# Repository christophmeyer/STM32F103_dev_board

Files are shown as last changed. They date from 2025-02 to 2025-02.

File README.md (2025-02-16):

# STM32F103 Development Board

This repo contains the [KiCad](https://www.kicad.org/) hardware design files for a development board for the `STM32F103` MCU, which is somewhat similar to the well known blue pill board. The design(er) has greatly benefitted from some of [Phil Salmony's](https://www.phils-lab.net/) designs :pray:.

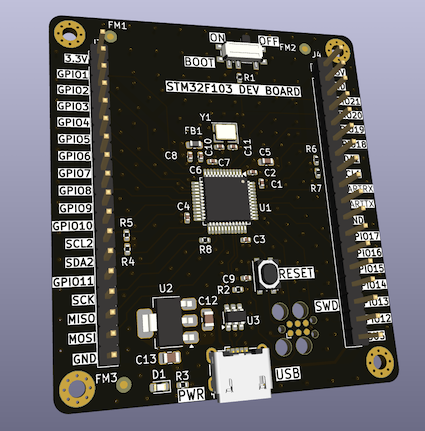
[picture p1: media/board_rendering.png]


## Features

- STM32F103 MCU
  - 2x I2C (pull up resistors included)
  - SPI (22R series termination resistor included)
  - USB micro
  - UART
  - 21 GPIOs
- 16MHz crystal
- ESD protection
- SWD via legged 6-pin plug-of-nails tag-connect connector
- BOOT0 pin toggle switch
- NRST pin push button
- Power LED
- LDO voltage regulator

## Manufacturing

All files necessary for manufacturing the board at the pcb manufacturer of your choice can be found in `./manufacturing_r0.1`. This includes the drill files, gerbers, bill of materials and a basic assembly drawing.

Fully manufactured version of the board:

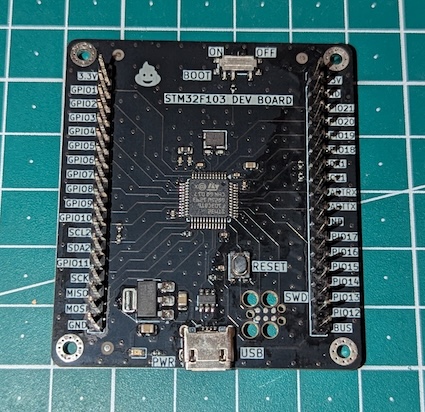
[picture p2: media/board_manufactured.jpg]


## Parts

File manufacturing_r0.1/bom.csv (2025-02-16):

Reference | Value | Datasheet | Footprint | Qty | Description | Manufacturer | Manufacturer Part Number | Distributor Link | Distributor Part Number
C1,C2,C3,C4,C9 | 100n | ~ | Capacitor_SMD:C_0402_1005Metric | 5 | Unpolarized capacitor | KYOCERA AVX | 04023C104KAT2A | https://www.mouser.de/ProductDetail/KYOCERA-AVX/04023C104KAT2A?qs=nNezP%252BoerbAsgsxxIAjFOw%3D%3D | 581-04023C104KAT2A
C5 | 10u | ~ | Capacitor_SMD:C_0603_1608Metric | 1 | Unpolarized capacitor | KYOCERA AVX | 0603YD106KAT2A | https://www.mouser.de/ProductDetail/KYOCERA-AVX/0603YD106KAT2A | 581-0603YD106KAT2A
C6,C8 | 1u | ~ | Capacitor_SMD:C_0402_1005Metric | 2 | Unpolarized capacitor | KYOCERA AVX | 04023D105KAT2A | https://www.mouser.de/ProductDetail/KYOCERA-AVX/04023D105KAT2A | 581-04023D105KAT2A
C7 | 10n | ~ | Capacitor_SMD:C_0402_1005Metric | 1 | Unpolarized capacitor | KYOCERA AVX | 0402YC104JAT4A | https://eu.mouser.com/ProductDetail/KYOCERA-AVX/0402YC104JAT4A | 581-0402YC104JAT4A
C10,C11 | 15p | ~ | Capacitor_SMD:C_0402_1005Metric | 2 | Unpolarized capacitor | KYOCERA AVX | 04025U150JAT2A | https://www.mouser.de/ProductDetail/KYOCERA-AVX/04025U150JAT2A
C12,C13 | 22u | ~ | Capacitor_SMD:C_0805_2012Metric | 2 | Unpolarized capacitor | KYOCERA AVX | 08053D226MAT2A | https://www.mouser.de/ProductDetail/KYOCERA-AVX/08053D226MAT2A?qs=bxXxiBiblXqtZp79ClJbtg%3D%3D | 581-08053D226MAT2A
D1 | LED | ~ | LED_SMD:LED_0603_1608Metric | 1 | Light emitting diode | Würth Elektronik | 150060SS75000 | https://www.digikey.de/en/products/detail/w%C3%BCrth-elektronik/150060SS75000/4489903 | 732-4979-2-ND
FB1 | 120R | ~ | Inductor_SMD:L_0603_1608Metric | 1 | Ferrite bead | Würth Elektronik | 742792606 | https://www.mouser.de/ProductDetail/Wurth-Elektronik/742792606?qs=Wn16VcyqZWrBgQf2cBsziw%3D%3D | 710-742792606
J1 | USB_B_Micro | ~ | Connector_USB:USB_Micro-B_Wuerth_629105150521 | 1 | USB Micro Type B connector | Würth Elektronik | 629105150521 | https://www.digikey.de/en/products/detail/w%C3%BCrth-elektronik/629105150521/5047751 | 732-5960-2-ND
R1 | 10k | ~ | Resistor_SMD:R_0402_1005Metric | 1 | Resistor | Würth Elektronik | 560112110020 | https://www.mouser.de/ProductDetail/Wurth-Elektronik/560112110020?qs=mELouGlnn3fA8%252B%2F79%2FueqA%3D%3D | 710-560112110020
R2,R3,R4,R5,R6,R7 | 1k5 | ~ | Resistor_SMD:R_0402_1005Metric | 6 | Resistor | Würth Elektronik | 560112110095 | https://www.mouser.de/ProductDetail/Wurth-Elektronik/560112110095?qs=mELouGlnn3cs5mmpxmgsuw%3D%3D | 710-560112110095
R8 | 22R | ~ | Resistor_SMD:R_0402_1005Metric | 1 | Resistor | Würth Elektronik | 560112110046 | https://www.mouser.de/ProductDetail/Wurth-Elektronik/560112110046?qs=mELouGlnn3e%252BO26rgRVUuA%3D%3D | 710-560112110046
SW1 | SW_Push | ~ | Button_Switch_SMD:SW_Push_1P1T_NO_Vertical_Wuerth_434133025816 | 1 | Push button switch, generic, two pins | Würth Elektronik | 434133025816 | https://www.digikey.de/en/products/detail/w%C3%BCrth-elektronik/434133025816/9950810 | 732-13663-2-ND
SW2 | SW_SPDT | ~ | Button_Switch_SMD:SW_SPDT_PCM12 | 1 | Switch, single pole double throw | C&K | PCM12SMTR | https://www.digikey.com/en/products/detail/c-k/PCM12SMTR/1640112 | 401-2016-2-ND
U1 | STM32F103C8Tx | https://www.st.com/resource/en/datasheet/stm32f103c8.pdf | Package_QFP:LQFP-48_7x7mm_P0.5mm | 1 | STMicroelectronics Arm Cortex-M3 MCU, 64KB flash, 20KB RAM, 72 MHz, 2.0-3.6V, 37 GPIO, LQFP48 | STMicroelectronics | STM32F103C8T6TR | https://www.digikey.com/en/products/detail/stmicroelectronics/STM32F103C8T6TR/2122442 | 497-17666-2-ND
U2 | AMS1117-3.3 | http://www.advanced-monolithic.com/pdf/ds1117.pdf | Package_TO_SOT_SMD:SOT-223-3_TabPin2 | 1 | 1A Low Dropout regulator, positive, 3.3V fixed output, SOT-223 | UMW | AMS1117-3.3 | https://www.digikey.de/en/products/detail/umw/AMS1117-3-3/17635254 | 4518-AMS1117-3.3TR-ND
U3 | USBLC6-2SC6 | https://www.st.com/resource/en/datasheet/usblc6-2.pdf | Package_TO_SOT_SMD:SOT-23-6 | 1 | Very low capacitance ESD protection diode, 2 data-line, SOT-23-6 | STMicroelectronics | USBLC6-2SC6Y | https://www.mouser.de/ProductDetail/STMicroelectronics/USBLC6-2SC6Y?qs=gNDSiZmRJS%2FOgDexvXkdow%3D%3D | 511-USBLC6-2SC6Y
Y1 | 16MHz | ~ | Crystal:Crystal_SMD_3225-4Pin_3.2x2.5mm | 1 | Four pin crystal, GND on pins 2 and 4 | NDK | NX3225GA-16.000M-STD-CRG-2 | https://www.mouser.in/ProductDetail/NDK/NX3225GA-16.000M-STD-CRG-2?qs=55YtniHzbhBNECTNQGAQ8A%3D%3D | 344-NX3225GA16MCRG2

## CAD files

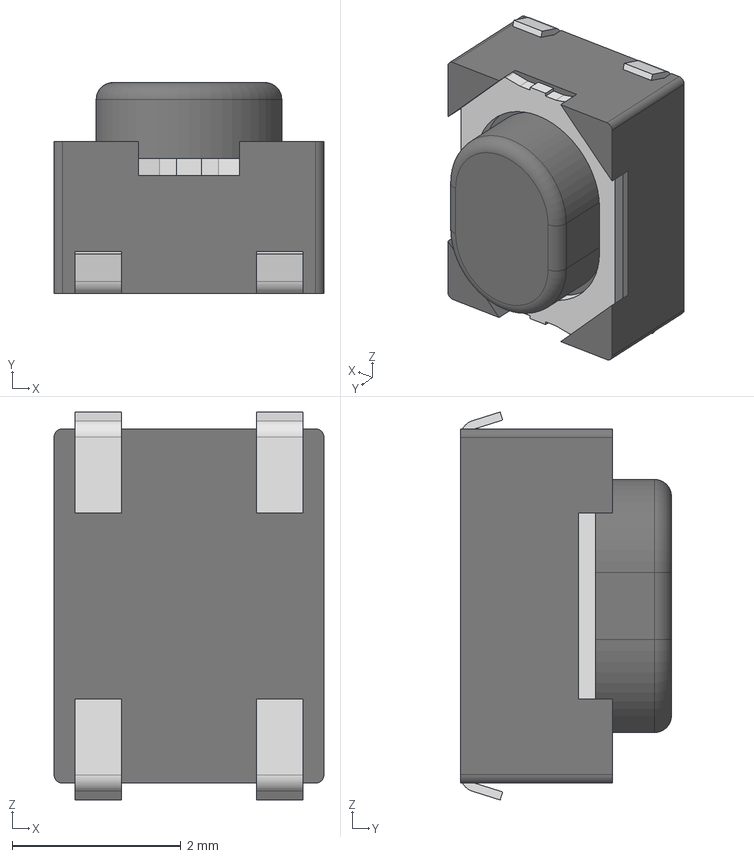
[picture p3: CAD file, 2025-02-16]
3d_models/STP_4341x30258x6_rev1.stp
3.20 x 2.50 x 4.60 mm
Frame
Cover
Stem
Terminal x 4

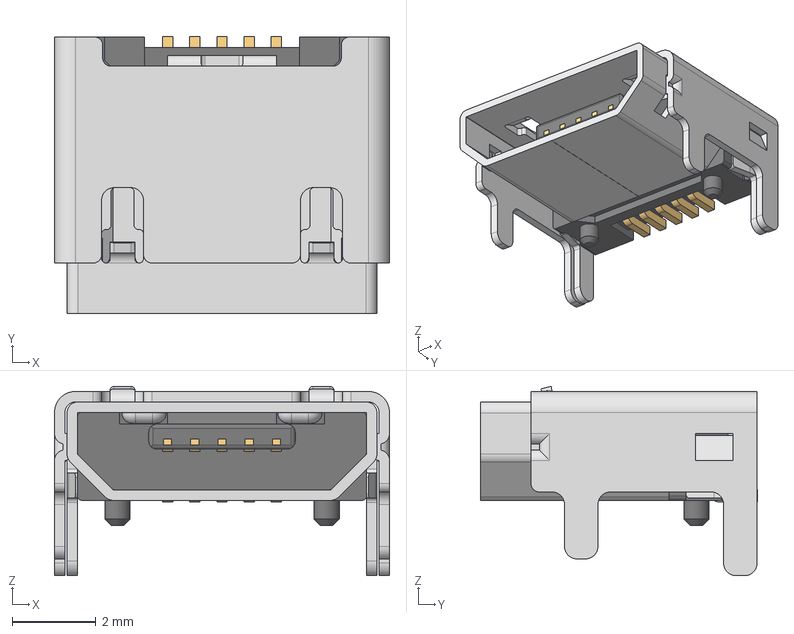
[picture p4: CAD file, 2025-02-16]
3d_models/629105150521 (rev1).stp
8.00 x 6.60 x 4.52 mm
629105150521_Housing
629105150521_Pin1 x 4
629105150521_Pin2
629105150521_Shielding2
629105150521_Shielding

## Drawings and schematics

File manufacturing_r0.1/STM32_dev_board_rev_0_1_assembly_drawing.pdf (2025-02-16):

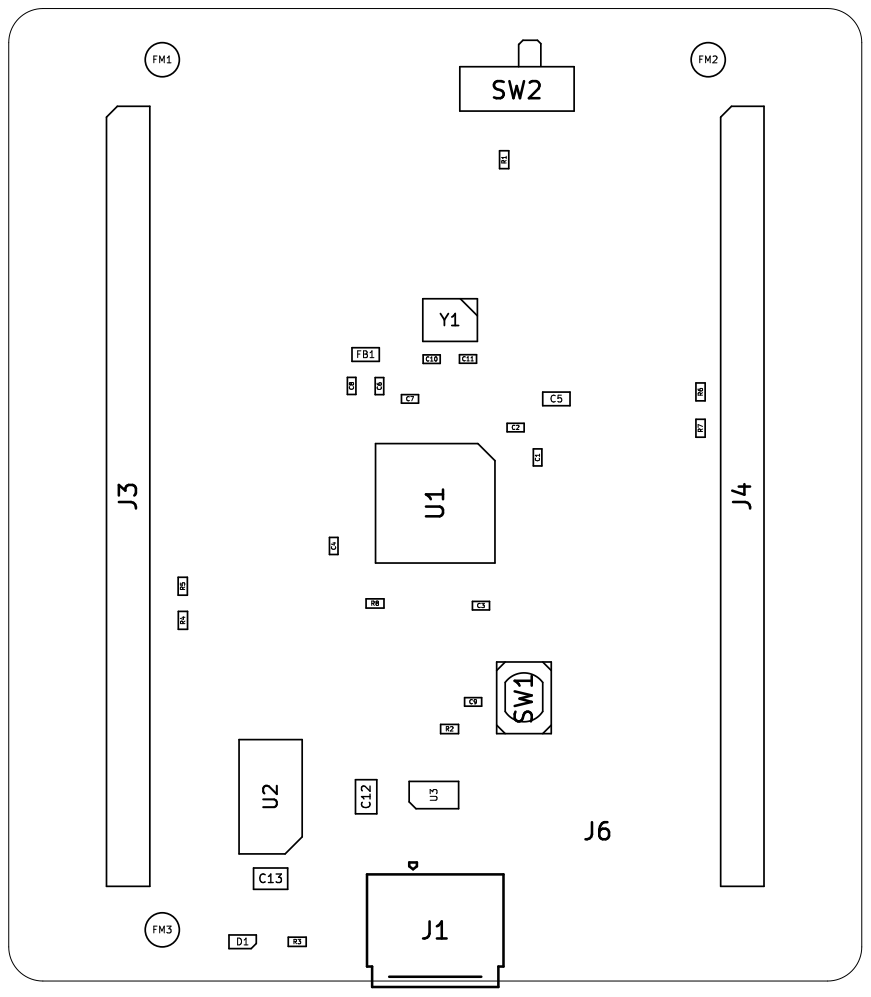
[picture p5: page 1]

Id: 1/1 Title: File: STM32_dev_board.kicad_pcb Sheet: SW1

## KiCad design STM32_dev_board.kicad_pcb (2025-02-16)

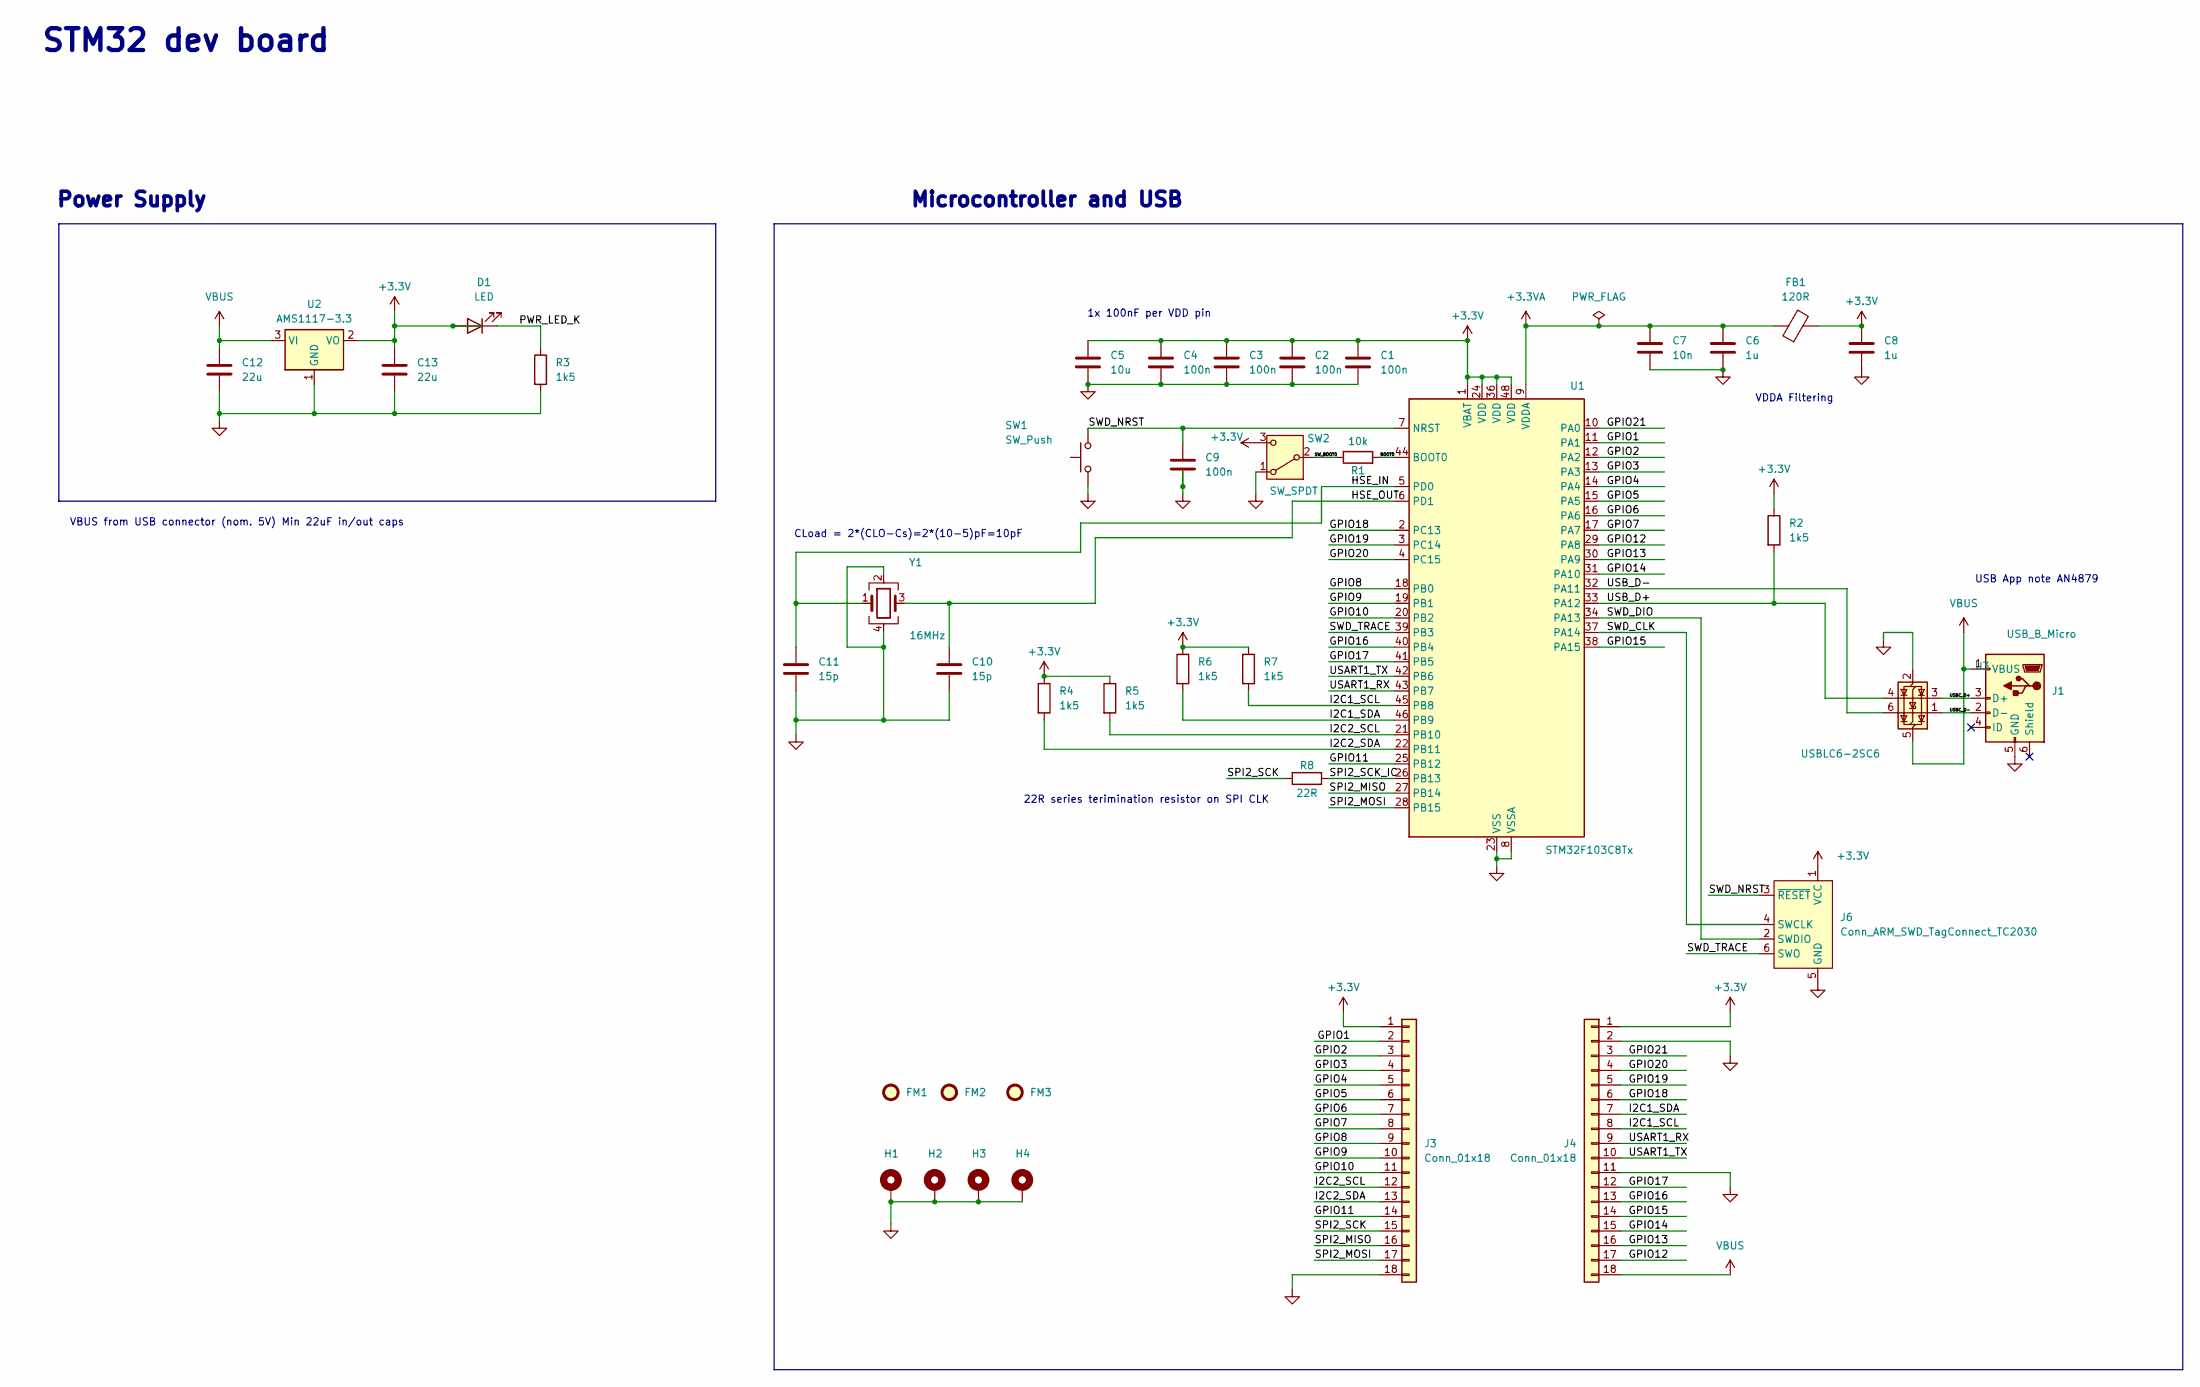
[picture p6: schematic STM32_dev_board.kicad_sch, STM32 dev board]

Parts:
C1, C2, C3, C4, C9: 100n; C_0402_1005Metric; Manufacturer Part Number 04023C104KAT2A
C5: 10u; C_0603_1608Metric; Manufacturer Part Number 0603YD106KAT2A
C6, C8: 1u; C_0402_1005Metric; Manufacturer Part Number 04023D105KAT2A
C7: 10n; C_0402_1005Metric; Manufacturer Part Number 0603YD475MAT2A
C10, C11: 15p; C_0402_1005Metric; Manufacturer Part Number 04025U150JAT2A
C12, C13: 22u; C_0805_2012Metric; Manufacturer Part Number 08053D226MAT2A
D1: LED; LED_0603_1608Metric; Manufacturer Part Number 150060SS75000
FB1: 120R; L_0603_1608Metric; Manufacturer Part Number 742792606
FM1, FM2, FM3: Fiducial; Fiducial_1mm_Mask2mm
H1, H2, H3, H4: MountingHole_Pad; MountingHole_2.2mm_M2_Pad_Via
J1: USB_B_Micro; USB_Micro-B_Wuerth_629105150521; Manufacturer Part Number 629105150521
J3, J4: Conn_01x18; PinHeader_1x18_P2.54mm_Vertical
J6: Conn_ARM_SWD_TagConnect_TC2030; Tag-Connect_TC2030-IDC-FP_2x03_P1.27mm_Vertical
R1: 10k; R_0402_1005Metric; Manufacturer Part Number 560112110020
R2, R3, R4, R5, R6, R7: 1k5; R_0402_1005Metric; Manufacturer Part Number 560112110095
R8: 22R; R_0402_1005Metric; Manufacturer Part Number 560112110046
SW1: SW_Push; SW_Push_1P1T_NO_Vertical_Wuerth_434133025816; Manufacturer Part Number 434133025816
SW2: SW_SPDT; SW_SPDT_PCM12; Manufacturer Part Number PCM12SMTR
U1: STM32F103C8Tx; LQFP-48_7x7mm_P0.5mm; Manufacturer Part Number STM32F103C8T6TR
U2: AMS1117-3.3; SOT-223-3_TabPin2; Manufacturer Part Number AMS1117-3.3
U3: USBLC6-2SC6; SOT-23-6; Manufacturer Part Number USBLC6-2SC6Y
Y1: 16MHz; Crystal_SMD_3225-4Pin_3.2x2.5mm; Manufacturer Part Number NX3225GA-16.000M-STD-CRG-2

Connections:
+3.3V: C1.1, C2.1, C3.1, C4.1, C5.1, C8.1, C13.1, D1.2 (A), FB1.2, J3.1, J4.1, J6.1 (VCC), R2.1, R4.1, R5.1, R6.1, R7.1, SW2.3 (C), U1.1 (VBAT), U1.24 (VDD), U1.36 (VDD), U1.48 (VDD), U2.2 (VO)
+3.3VA: C6.1, C7.1, FB1.1, U1.9 (VDDA)
/BOOT0: R1.2, U1.44 (BOOT0)
/GPIO1: J3.2, U1.11 (PA1)
/GPIO2: J3.3, U1.12 (PA2)
/GPIO3: J3.4, U1.13 (PA3)
/GPIO4: J3.5, U1.14 (PA4)
/GPIO5: J3.6, U1.15 (PA5)
/GPIO6: J3.7, U1.16 (PA6)
/GPIO7: J3.8, U1.17 (PA7)
/GPIO8: J3.9, U1.18 (PB0)
/GPIO9: J3.10, U1.19 (PB1)
/GPIO10: J3.11, U1.20 (PB2)
/GPIO11: J3.14, U1.25 (PB12)
/GPIO12: J4.17, U1.29 (PA8)
/GPIO13: J4.16, U1.30 (PA9)
/GPIO14: J4.15, U1.31 (PA10)
/GPIO15: J4.14, U1.38 (PA15)
/GPIO16: J4.13, U1.40 (PB4)
/GPIO17: J4.12, U1.41 (PB5)
/GPIO18: J4.6, U1.2 (PC13)
/GPIO19: J4.5, U1.3 (PC14)
/GPIO20: J4.4, U1.4 (PC15)
/GPIO21: J4.3, U1.10 (PA0)
/HSE_IN: C11.1, U1.5 (PD0), Y1.1
/HSE_OUT: C10.1, U1.6 (PD1), Y1.3
/I2C1_SCL: J4.8, R7.2, U1.45 (PB8)
/I2C1_SDA: J4.7, R6.2, U1.46 (PB9)
/I2C2_SCL: J3.12, R5.2, U1.21 (PB10)
/I2C2_SDA: J3.13, R4.2, U1.22 (PB11)
/PWR_LED_K: D1.1 (K), R3.1
/SPI2_MISO: J3.16, U1.27 (PB14)
/SPI2_MOSI: J3.17, U1.28 (PB15)
/SPI2_SCK: J3.15, R8.2
/SPI2_SCK_IC: R8.1, U1.26 (PB13)
/SWD_CLK: J6.4 (SWCLK), U1.37 (PA14)
/SWD_DIO: J6.2 (SWDIO), U1.34 (PA13)
/SWD_NRST: C9.1, J6.3 (~RESET), SW1.2, U1.7 (NRST)
/SWD_TRACE: J6.6 (SWO), U1.39 (PB3)
/SW_BOOT0: R1.1, SW2.2 (B)
/USART1_RX: J4.9, U1.43 (PB7)
/USART1_TX: J4.10, U1.42 (PB6)
/USBC_D+: J1.3 (D+), U3.3 (I/O2)
/USBC_D-: J1.2 (D-), U3.1 (I/O1)
/USB_D+: R2.2, U1.33 (PA12), U3.4 (I/O2)
/USB_D-: U1.32 (PA11), U3.6 (I/O1)
GND: C1.2, C2.2, C3.2, C4.2, C5.2, C6.2, C7.2, C8.2, C9.2, C10.2, C11.2, C12.2, C13.2, H1.1, H2.1, H3.1, H4.1, J1.5 (GND), J3.18, J4.2, J4.11, J6.5 (GND), R3.2, SW1.1, SW2.1 (A), U1.8 (VSSA), U1.23 (VSS), U1.35 (VSS), U1.47 (VSS), U2.1 (GND), U3.2 (GND), Y1.2, Y1.4
VBUS: C12.1, J1.1 (VBUS), J4.18, U2.3 (VI), U3.5 (VBUS)

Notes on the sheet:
Power Supply
VDDA Filtering
1x 100nF per VDD pin
VBUS from USB connector (nom. 5V) Min 22uF in/out caps
STM32 dev board
USB App note AN4879
22R series terimination resistor on SPI CLK
Microcontroller and USB
CLoad = 2*(CLO-Cs)=2*(10-5)pF=10pF

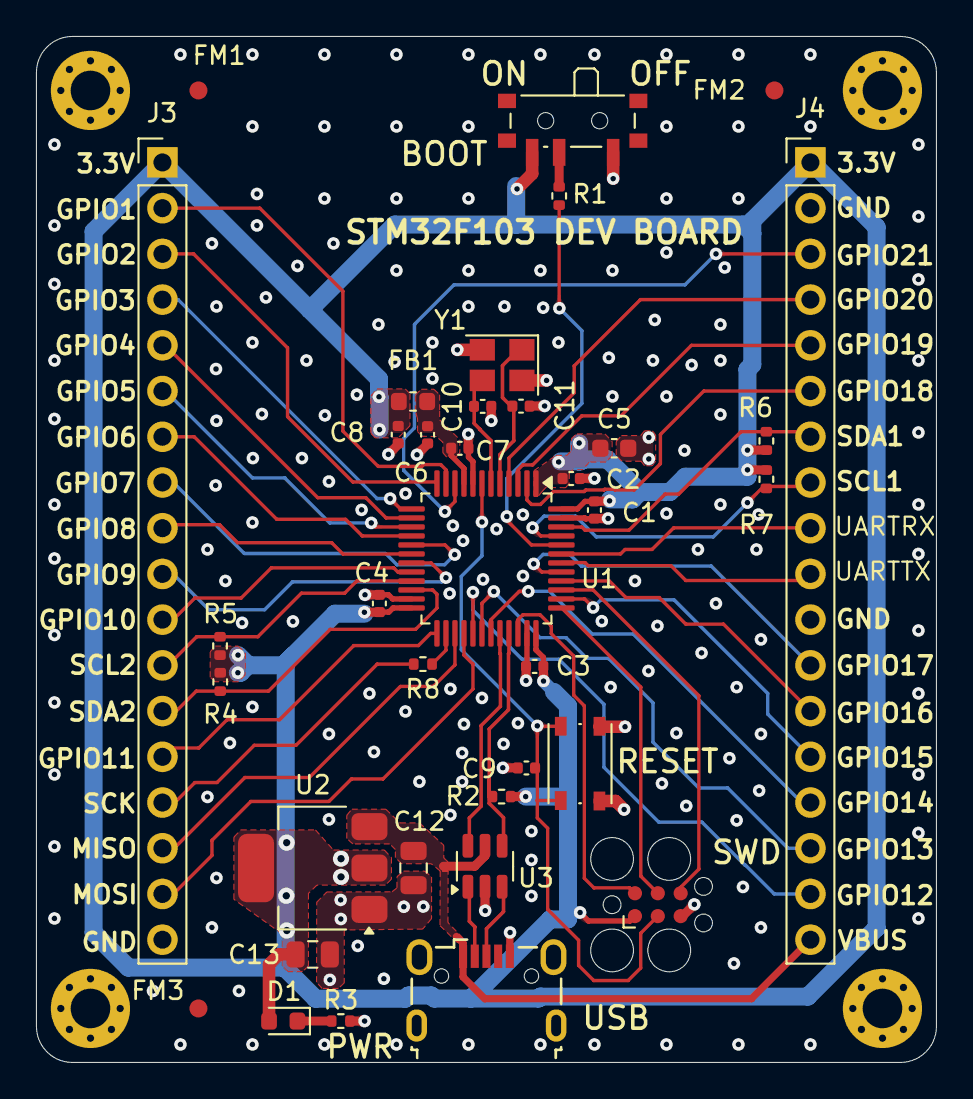
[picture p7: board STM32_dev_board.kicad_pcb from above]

Board: 4 copper layers, 50.0 x 57.0 mm, 40 parts (0 on the bottom side), 48 nets.
